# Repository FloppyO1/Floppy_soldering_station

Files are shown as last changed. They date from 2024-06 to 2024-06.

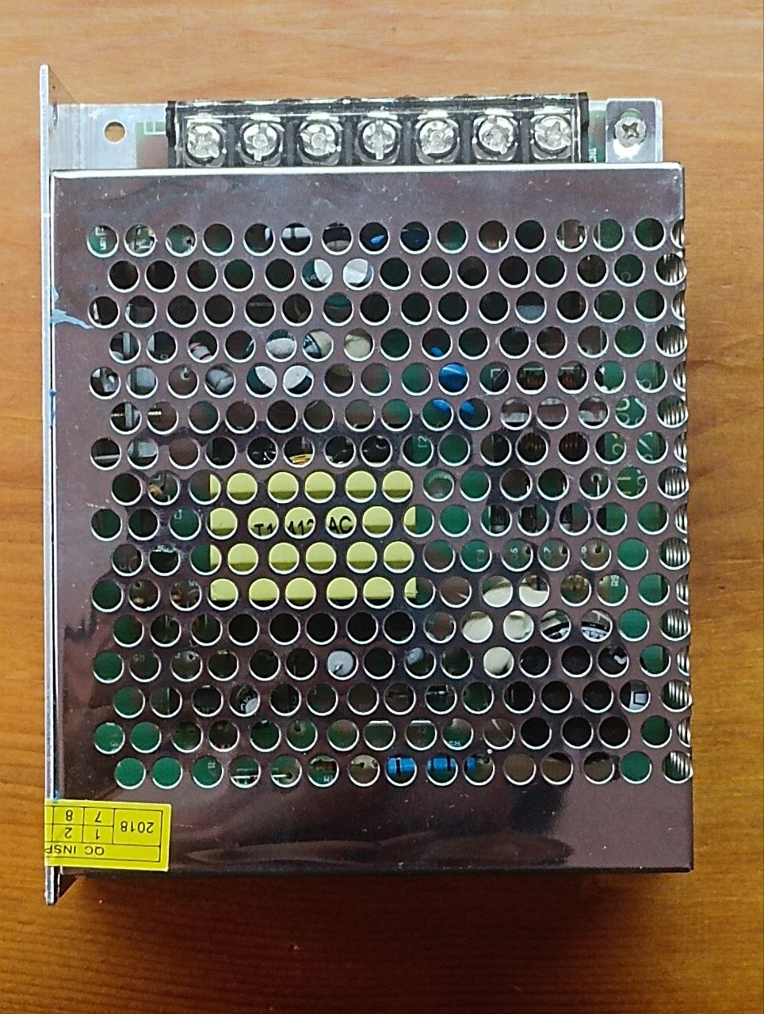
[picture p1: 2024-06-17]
CASE/components/power supply/up.jpg

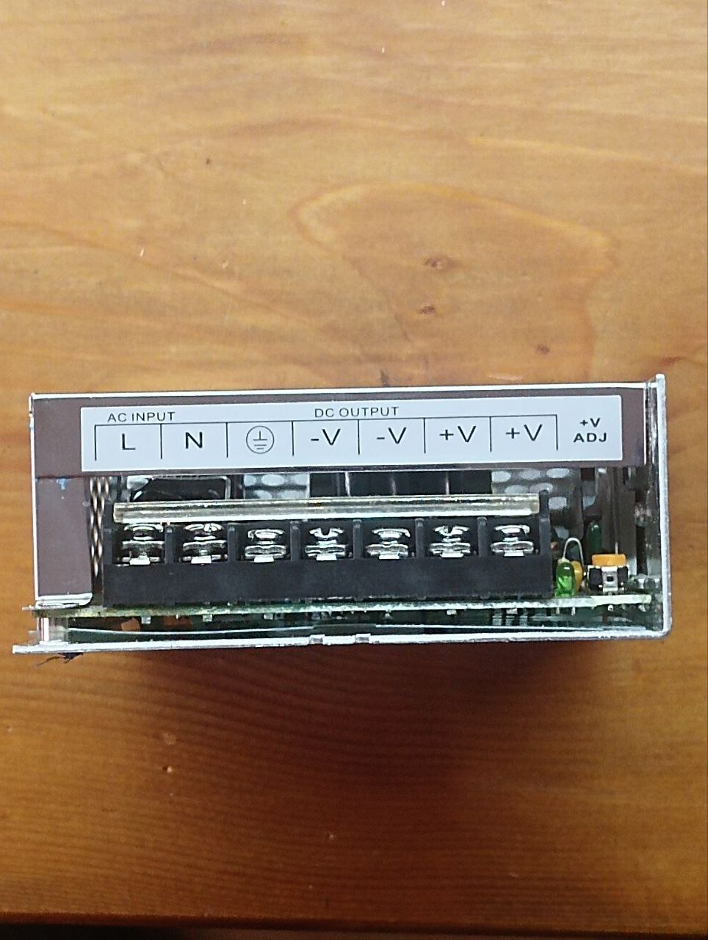
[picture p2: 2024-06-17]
CASE/components/power supply/front.jpg

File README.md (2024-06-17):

## Floppy Soldering Station v3.0
The Floppy soldering station 3.0 is a DIY soldering station, easy to make and inexpensive. It is great for learning and having a good workshop tool at the same time.





https://youtu.be/hezzL1TSIhk

## Support this project with a donation

To support this project you can make a donation via PayPal or buy a Floppy Board:

https://www.paypal.com/paypalme/floppylab

https://ko-fi.com/floppylab

## License

[CERN Open Hardware Licence Version 2 - Strongly Reciprocal](https://choosealicense.com/licenses/cern-ohl-s-2.0/#)



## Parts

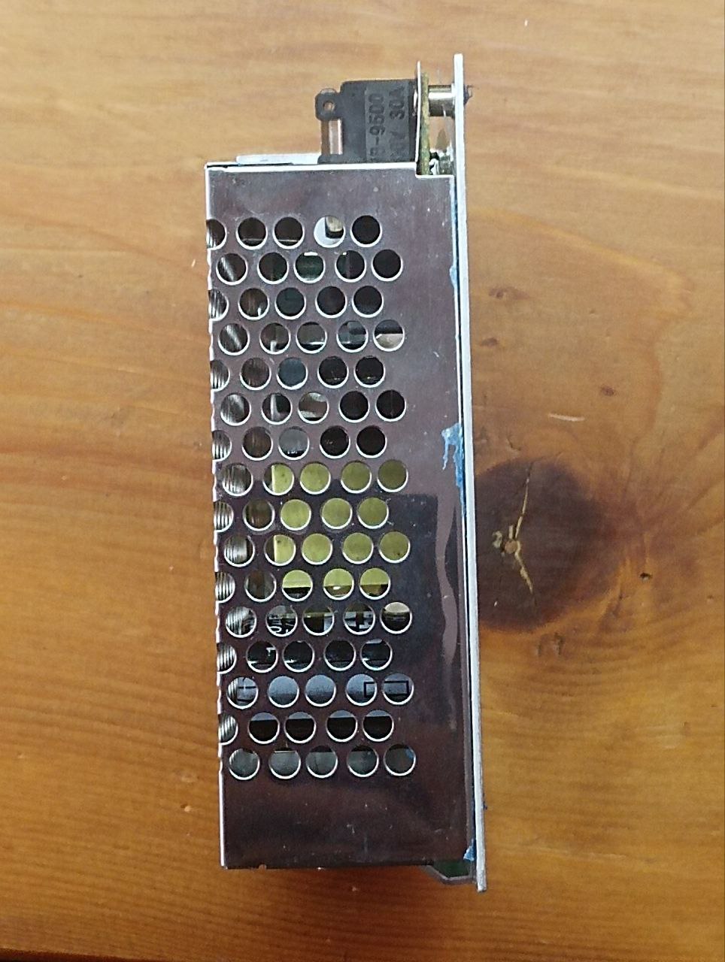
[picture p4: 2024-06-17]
CASE/components/power supply/right.jpg

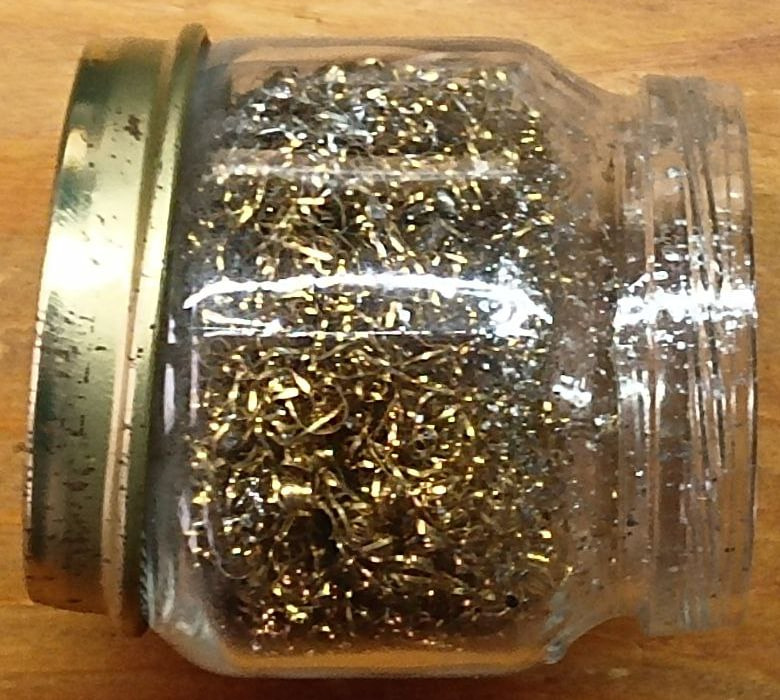
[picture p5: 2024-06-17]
CASE/components/brass scourer cup.jpg

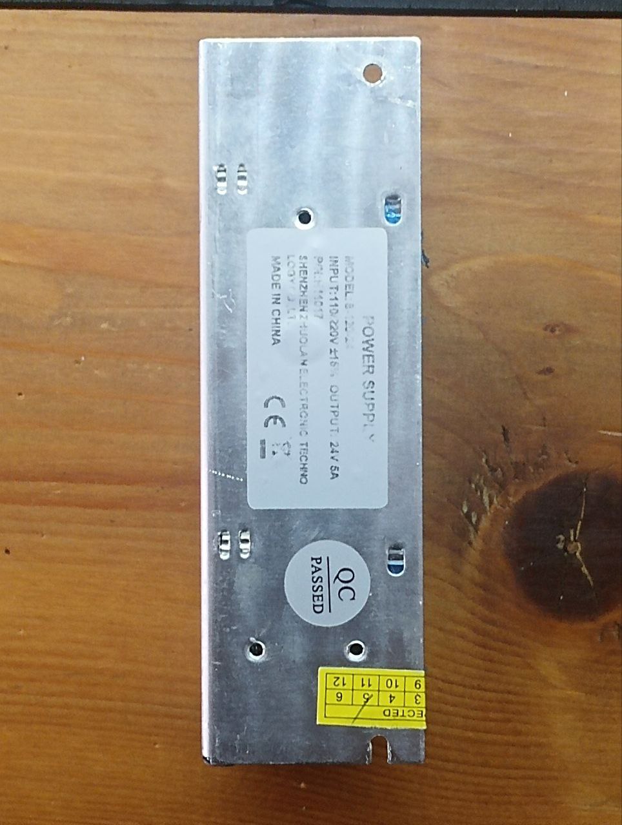
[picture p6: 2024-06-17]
CASE/components/power supply/left.jpg

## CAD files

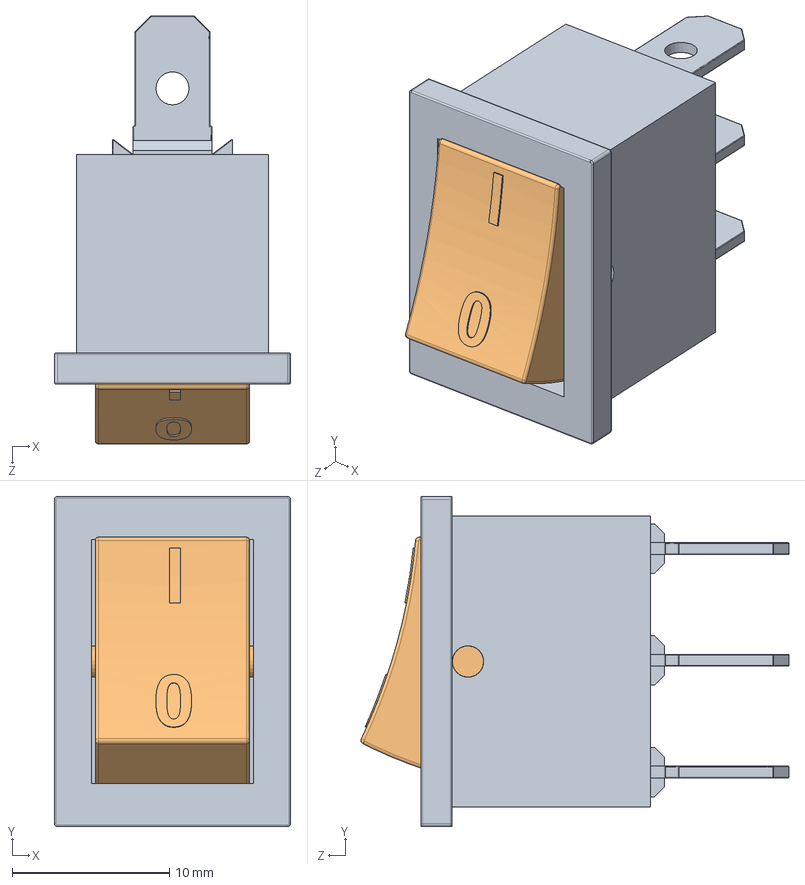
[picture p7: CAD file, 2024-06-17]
CASE/components/Power Switch.SLDASM
15.0 x 21.0 x 27.2 mm
F6vde.stp
Lambalı Anahtar - Tuş.stp
Lambalı Anahtar - Tuş arkası.stp

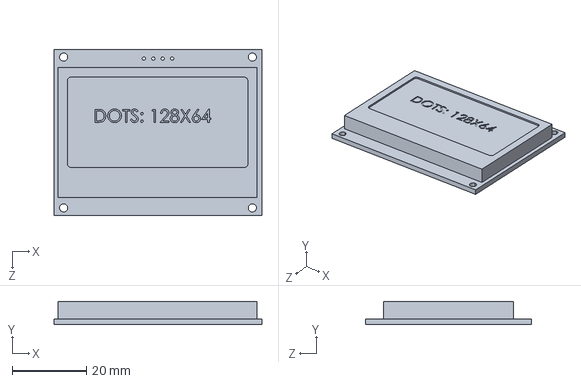
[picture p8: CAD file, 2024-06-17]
CASE/components/LCD-GM12864-59N.SLDPRT
56.0 x 6.30 x 44.6 mm

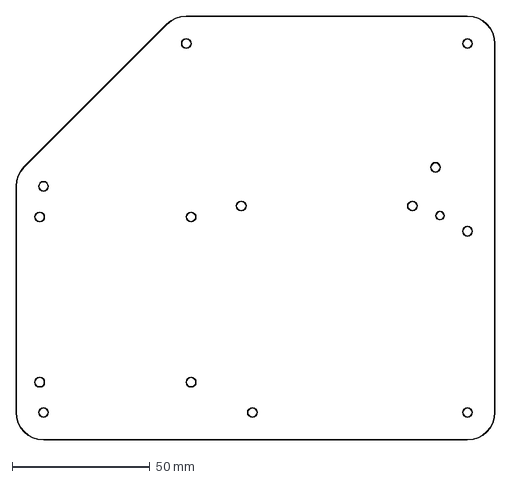
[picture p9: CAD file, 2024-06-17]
CASE/laser/case right.DXF
174.0 x 154.0 mm

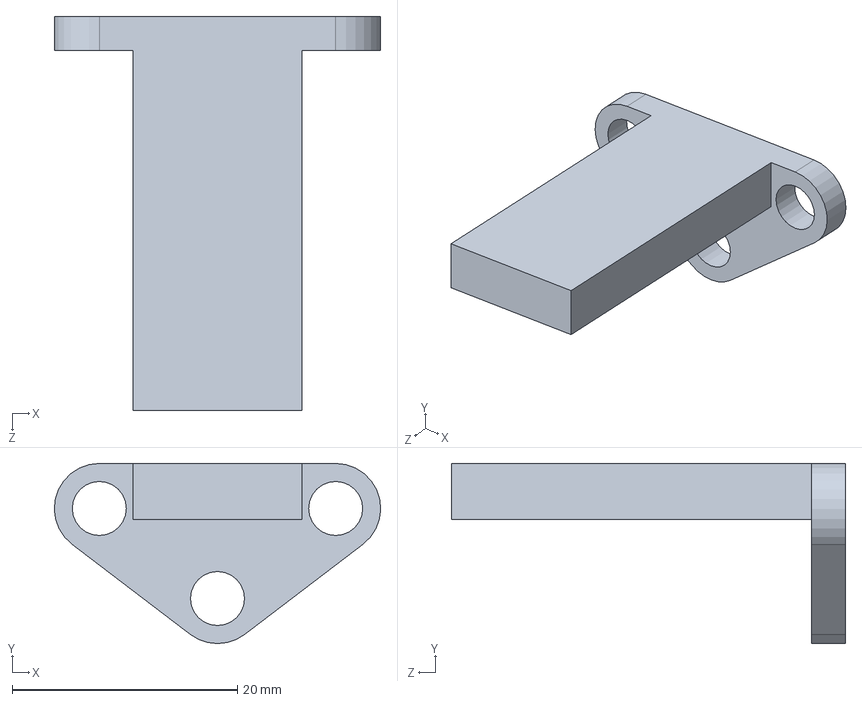
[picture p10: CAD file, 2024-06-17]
CASE/power supply holder 2.SLDPRT
29.0 x 16.0 x 35.0 mm

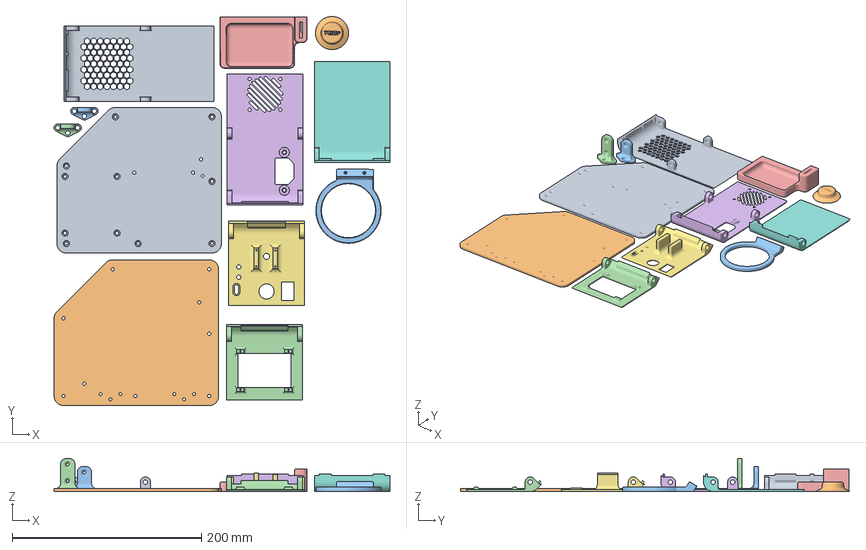
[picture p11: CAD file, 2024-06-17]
CASE/to be printed/case.3MF
355.1 x 411.2 x 35.0 mm

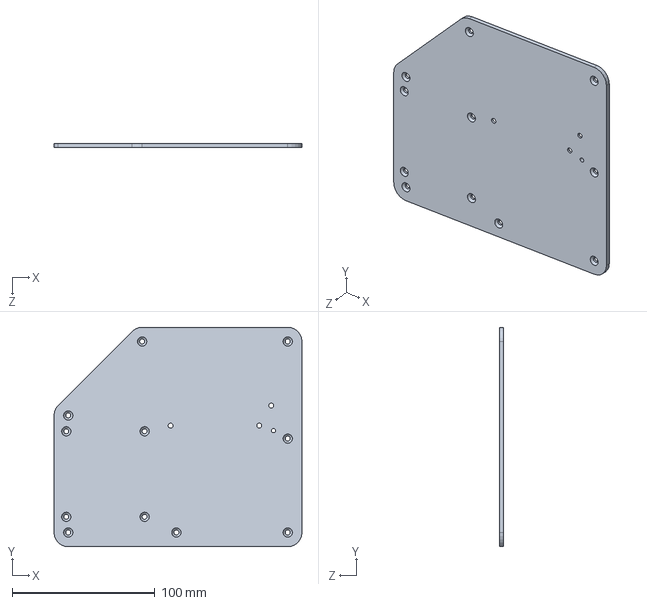
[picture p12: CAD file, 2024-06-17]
CASE/case right.SLDPRT
174.0 x 154.0 x 3.00 mm

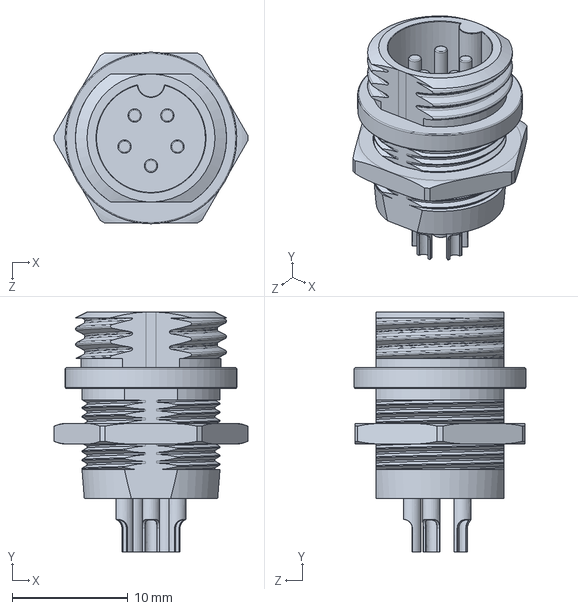
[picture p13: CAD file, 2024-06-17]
CASE/components/GX12-5P .SLDPRT
16.7 x 20.7 x 14.8 mm

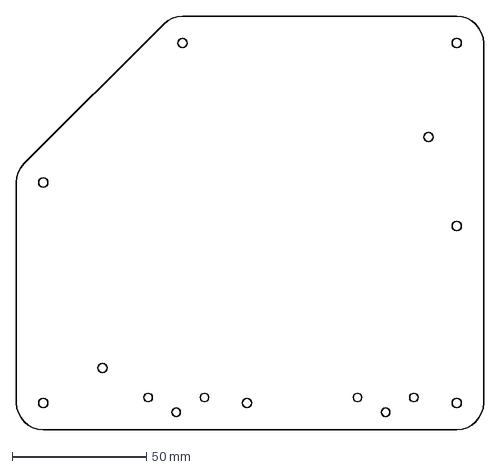
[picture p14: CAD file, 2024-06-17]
CASE/laser/case left.DXF
174.0 x 154.0 mm

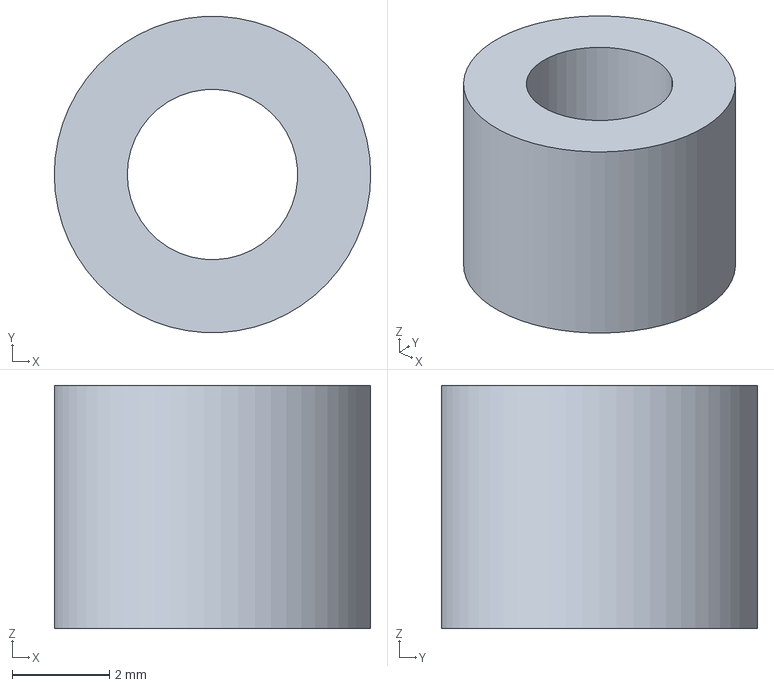
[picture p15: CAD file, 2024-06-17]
CASE/to be printed/PCB spacer.3MF
6.50 x 6.49 x 5.00 mm

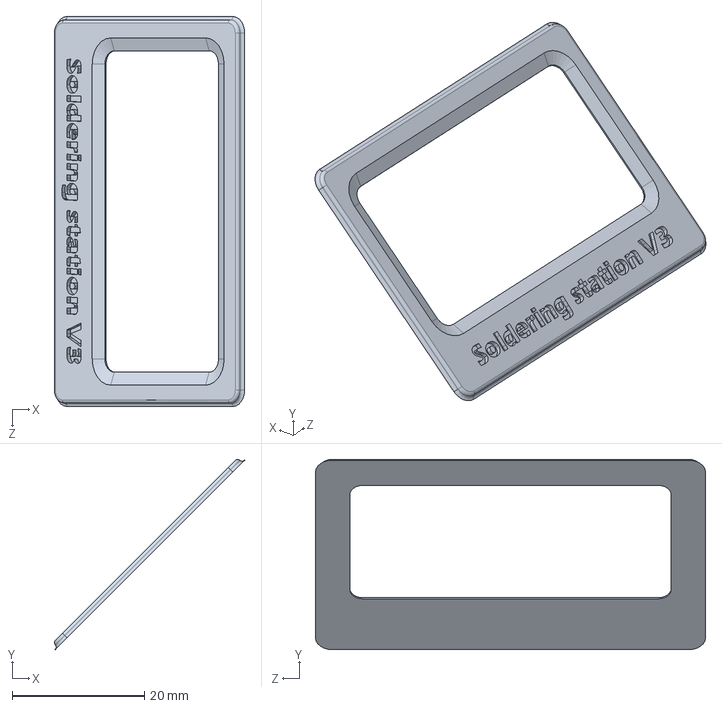
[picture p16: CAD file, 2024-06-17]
CASE/display mask.SLDPRT
28.8 x 28.8 x 59.0 mm

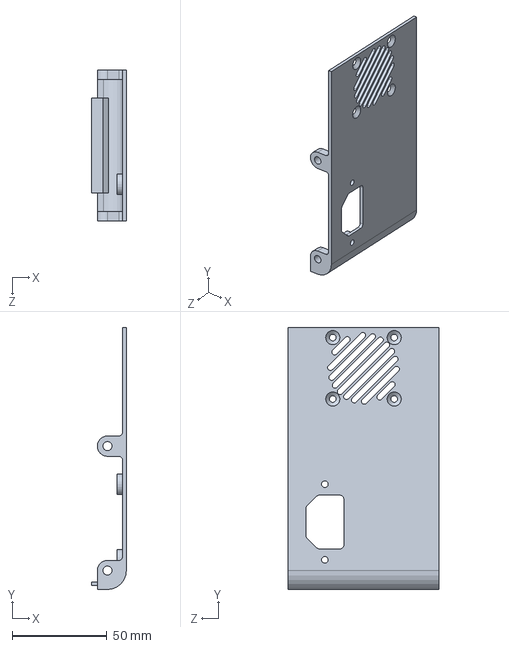
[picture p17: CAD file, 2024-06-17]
CASE/case 4.SLDPRT
18.4 x 138.6 x 80.0 mm

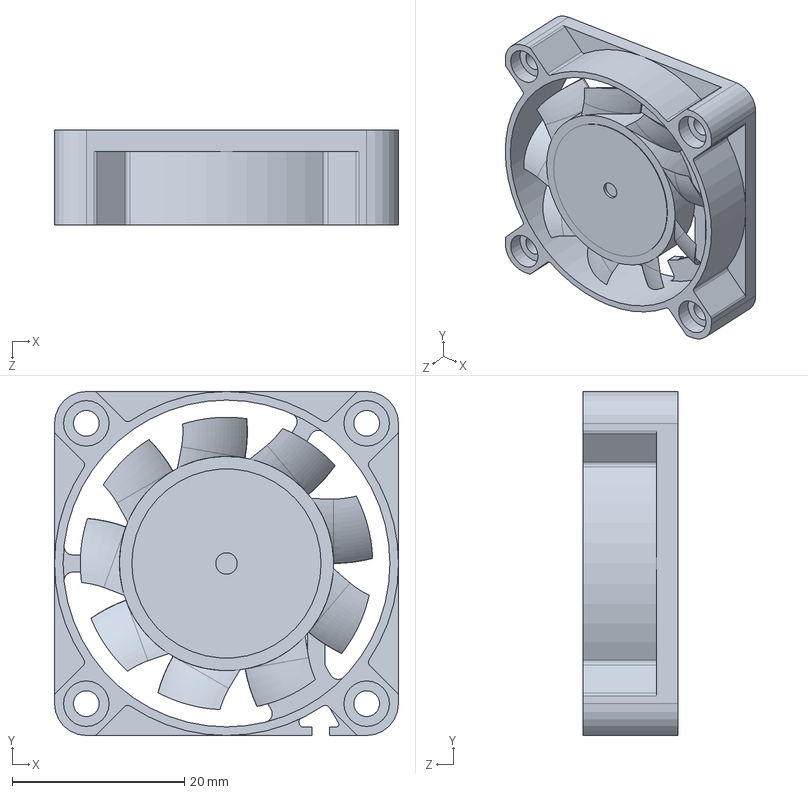
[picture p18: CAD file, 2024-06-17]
CASE/components/40x40x10 fan.SLDPRT
40.0 x 40.0 x 11.0 mm

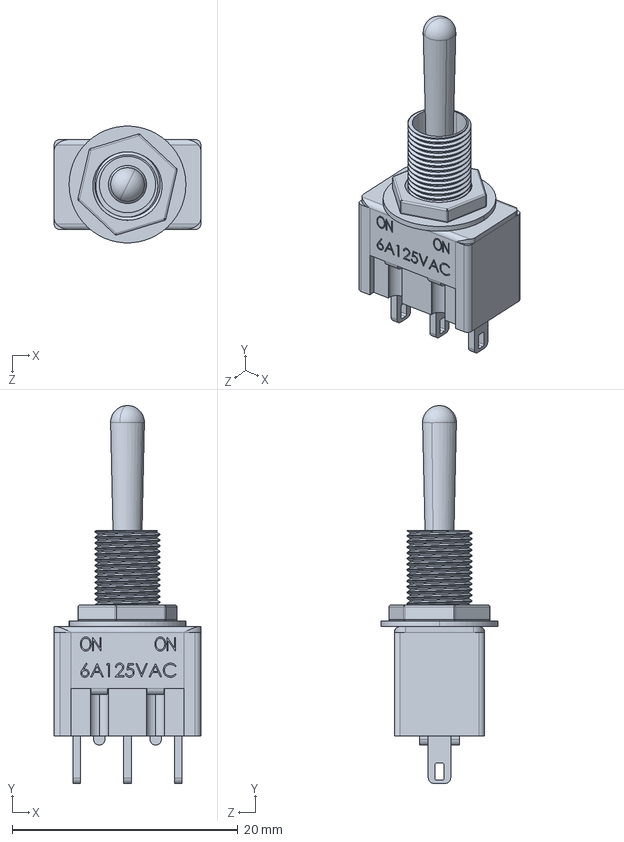
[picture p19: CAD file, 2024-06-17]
CASE/components/lever switch.SLDPRT
13.0 x 33.5 x 10.3 mm

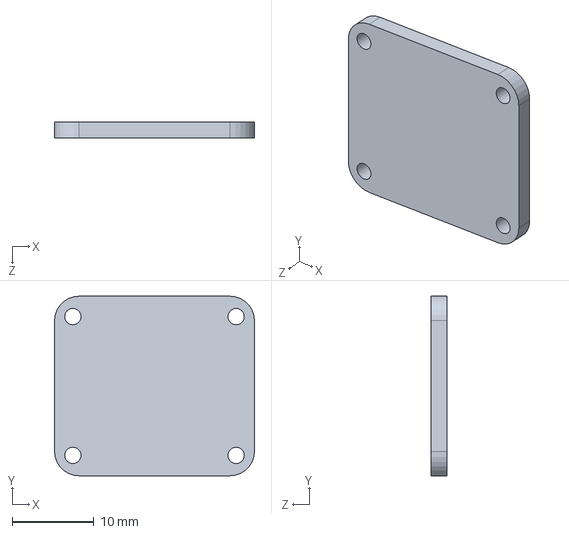
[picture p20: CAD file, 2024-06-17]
CASE/encoder holder.SLDPRT
24.5 x 22.0 x 2.00 mm

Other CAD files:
CASE/components/GX16-4P.SLDPRT
CASE/soldering iron holder.SLDPRT
CASE/components/C14 power plug.SLDPRT
CASE/power supply holder.SLDPRT
CASE/PCB_spacer.SLDPRT
CASE/brass scourer holder.SLDPRT
CASE/case 1.SLDPRT
CASE/case 2.SLDPRT
CASE/case 3.SLDPRT
CASE/case 5.SLDPRT
CASE/case base.SLDPRT
CASE/case left.SLDPRT
CASE/components/rotary+encoder_17mm_hole_spc.SLDPRT
CASE/knob.SLDPRT

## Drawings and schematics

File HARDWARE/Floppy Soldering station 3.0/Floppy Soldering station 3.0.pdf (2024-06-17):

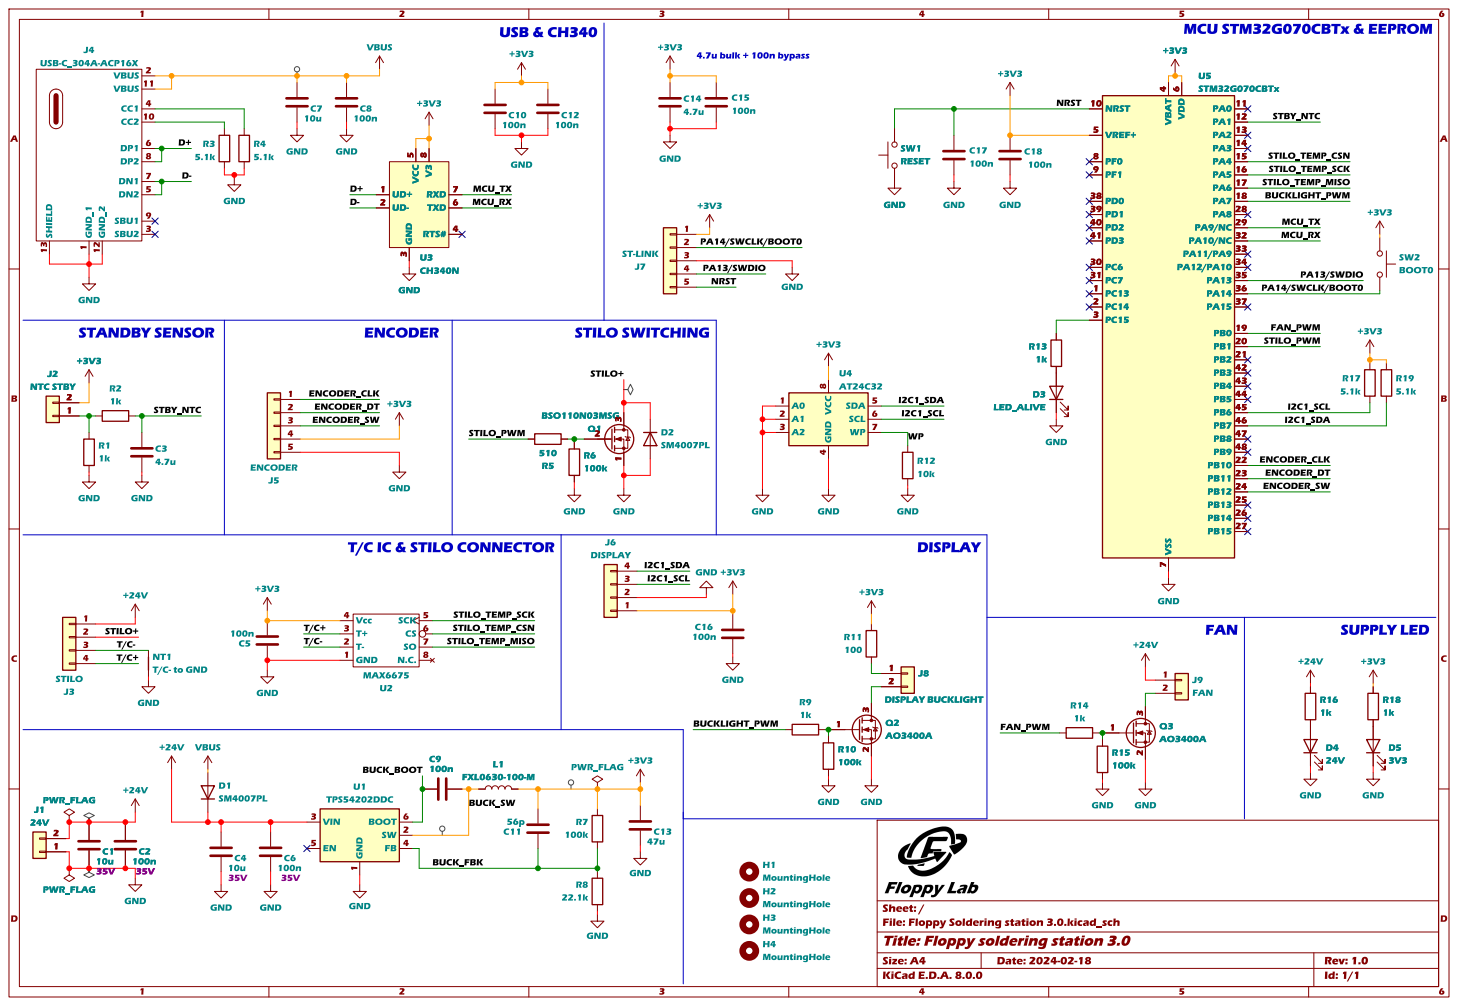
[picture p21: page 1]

File: Floppy Soldering station 3.0.kicad_sch Sheet: /
Id: 1/1 Title: Floppy soldering station 3.0

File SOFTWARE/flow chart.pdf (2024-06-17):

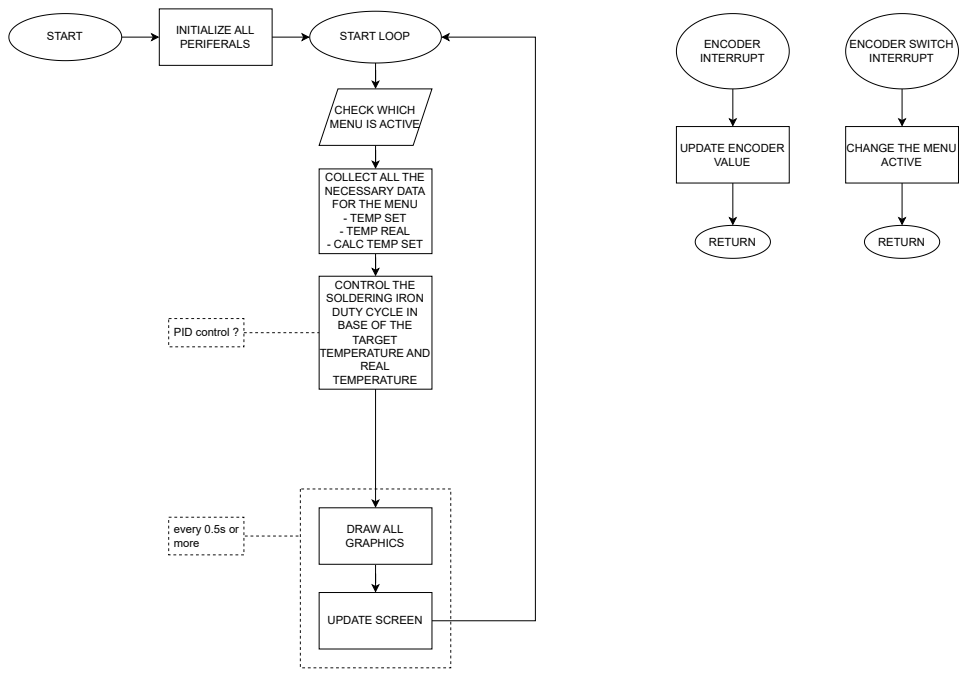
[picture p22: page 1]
START; INITIALIZE ALL; PERIFERALS; START LOOP; DRAW ALL GRAPHICS; UPDATE SCREEN; ENCODER INTERRUPT; UPDATE ENCODER VALUE; ENCODER SWITCH INTERRUPT; RETURN; REAL TEMPERATURE; every 0.5s or more; PID control ?

CHECK WHICH
MENU IS ACTIVE

CHANGE THE MENU
ACTIVE

COLLECT ALL THE
NECESSARY DATA
FOR THE MENU
- TEMP SET
- TEMP REAL
- CALC TEMP SET

CONTROL THE
SOLDERING IRON
DUTY CYCLE IN
BASE OF THE
TARGET
TEMPERATURE AND

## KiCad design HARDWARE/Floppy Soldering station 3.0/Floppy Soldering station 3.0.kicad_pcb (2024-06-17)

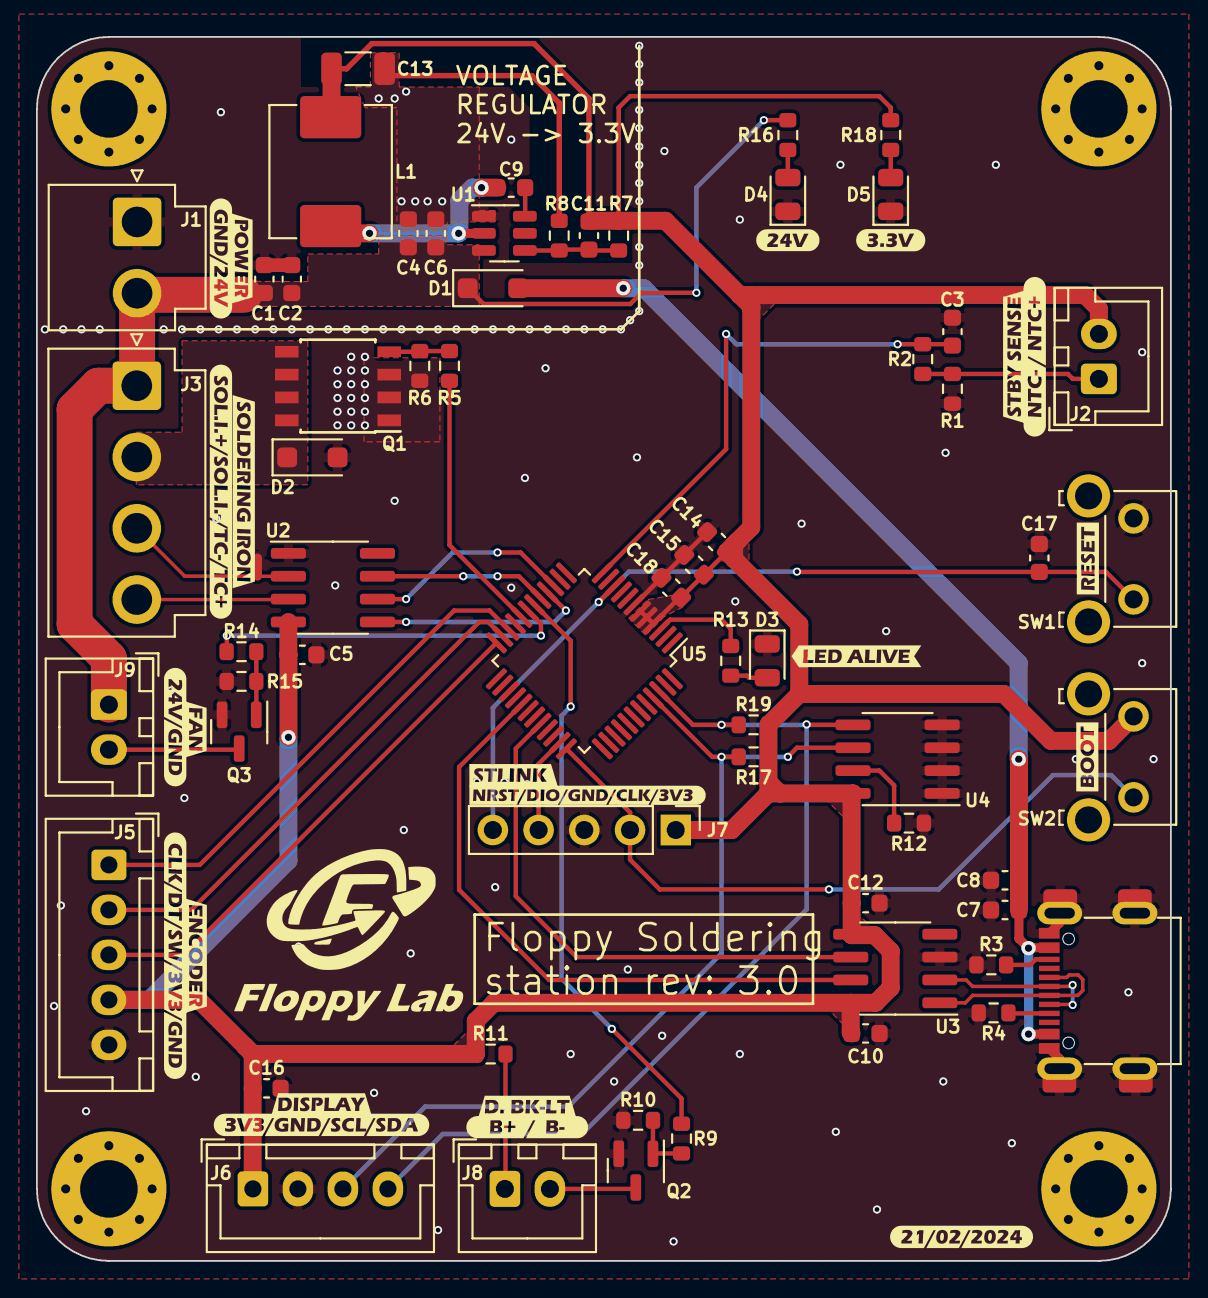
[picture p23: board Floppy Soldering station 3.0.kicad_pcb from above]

Board: 2 copper layers, 63.0 x 68.0 mm, 89 parts (0 on the bottom side), 43 nets.

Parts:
C1, C4, C7: 10u; C_0603_1608Metric
C2, C5, C6, C8, C9, C10, C12, C15, C16, C17, C18: 100n; C_0603_1608Metric
C3, C14: 4.7u; C_0603_1608Metric
C11: 56p; C_0603_1608Metric
C13: 47u; C_1206_3216Metric
D1, D2: SM4007PL; D_SOD-123F
D3: LED_ALIVE; LED_0805_2012Metric
D4: 24V; LED_0805_2012Metric
D5: 3V3; LED_0805_2012Metric
H1, H2, H3, H4: MountingHole; MountingHole_3.2mm_M3_Pad_Via
J1: 24V; JST_VH_B2P-VH-B_1x02_P3.96mm_Vertical
J2: NTC STBY; JST_XH_B2B-XH-A_1x02_P2.50mm_Vertical
J3: STILO; JST_VH_B4P-VH-B_1x04_P3.96mm_Vertical
J4: USB-C_304A-ACP16X; USB_C_304A-ACP16X
J5: ENCODER; JST_XH_B5B-XH-A_1x05_P2.50mm_Vertical
J6: DISPLAY; JST_XH_B4B-XH-A_1x04_P2.50mm_Vertical
J7: ST-LINK; PinHeader_1x05_P2.54mm_Vertical
J8: DISPLAY BUCKLIGHT; JST_XH_B2B-XH-A_1x02_P2.50mm_Vertical
J9: FAN; JST_XH_B2B-XH-A_1x02_P2.50mm_Vertical
L1: FXL0630-100-M; L_Abracon_ASPI-0630LR
NT1: T/C- to GND; NetTie-2_SMD_Pad0.5mm
Q1: BSO110N03MSG; PG-DSO-8
Q2, Q3: AO3400A; SOT-23
R1, R2, R9, R13, R14, R16, R18: 1k; R_0603_1608Metric
R3, R4, R17, R19: 5.1k; R_0603_1608Metric
R5: 510; R_0603_1608Metric
R6, R7, R10, R15: 100k; R_0603_1608Metric
R8: 22.1k; R_0603_1608Metric
R11: 100; R_0603_1608Metric
R12: 10k; R_0603_1608Metric
SW1: RESET; SW_SPST_Omron_B3F-315x_Angled
SW2: BOOT0; SW_SPST_Omron_B3F-315x_Angled
U1: TPS54202DDC; SOT-23-6
U2: MAX6675; SOIC-8_3.9x4.9mm_P1.27mm
U3: CH340N; SOIC-8_3.9x4.9mm_P1.27mm
U4: AT24C32; SOIC-8_3.9x4.9mm_P1.27mm
U5: STM32G070CBTx; LQFP-48_7x7mm_P0.5mm
kibuzzard-65D5CE26: G***; kibuzzard-65D5CE26
kibuzzard-65D5CEBD: G***; kibuzzard-65D5CEBD
kibuzzard-65D5D1B7: G***; kibuzzard-65D5D1B7
kibuzzard-65D5D1D2: G***; kibuzzard-65D5D1D2
kibuzzard-65D5D3BD: G***; kibuzzard-65D5D3BD
kibuzzard-65D5D3CA: G***; kibuzzard-65D5D3CA
kibuzzard-65D5D4B6: G***; kibuzzard-65D5D4B6
kibuzzard-65D5D4FE: G***; kibuzzard-65D5D4FE
kibuzzard-65D5D5E6: G***; kibuzzard-65D5D5E6
kibuzzard-65D5D7D5: G***; kibuzzard-65D5D7D5
kibuzzard-65D5D7E7: G***; kibuzzard-65D5D7E7
kibuzzard-65D5D32E: G***; kibuzzard-65D5D32E
kibuzzard-65D5D52E: G***; kibuzzard-65D5D52E
kibuzzard-65D5D69C: G***; kibuzzard-65D5D69C
kibuzzard-65D5D154: G***; kibuzzard-65D5D154
kibuzzard-65D5D342: G***; kibuzzard-65D5D342
kibuzzard-65D5D366: G***; kibuzzard-65D5D366
kibuzzard-65D5D519: G***; kibuzzard-65D5D519
kibuzzard-65D5D545: G***; kibuzzard-65D5D545
kibuzzard-65D5D557: G***; kibuzzard-65D5D557
kibuzzard-65D5D985: G***; kibuzzard-65D5D985
kibuzzard-65D705D3: G***; kibuzzard-65D705D3

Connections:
+3V3: C5.2, C10.1, C11.2, C12.1, C13.1, C14.1, C15.1, C16.1, C18.2, J2.2, J5.4, J6.1, J7.1, L1.2, R7.2, R11.2, R17.2, R18.1, R19.1, SW2.1, U2.4 (Vcc), U3.5 (VCC), U3.8 (V3), U4.8 (VCC), U5.4 (VBAT), U5.5 (VREF+), U5.6 (VDD)
+24V: C1.1, C2.1, C4.1, C6.1, D1.1 (K), J1.2, J3.1, J9.1, R16.1, U1.3 (VIN)
/BUCKLIGHT_PWM: R9.2, U5.18 (PA7)
/BUCK_BOOT: C9.2, U1.6 (BOOT)
/BUCK_FBK: C11.1, R7.1, R8.2, U1.4 (FB)
/BUCK_SW: C9.1, L1.1, U1.2 (SW)
/D+: J4.6 (DP1), J4.8 (DP2), U3.1 (UD+)
/D-: J4.5 (DN2), J4.7 (DN1), U3.2 (UD-)
/ENCODER_CLK: J5.1, U5.22 (PB10)
/ENCODER_DT: J5.2, U5.23 (PB11)
/ENCODER_SW: J5.3, U5.24 (PB12)
/FAN_PWM: R14.2, U5.19 (PB0)
/I2C1_SCL: J6.3, R17.1, U4.6 (SCL), U5.45 (PB6)
/I2C1_SDA: J6.4, R19.2, U4.5 (SDA), U5.46 (PB7)
/MCU_RX: U3.6 (TXD), U5.32 (PA10/NC)
/MCU_TX: U3.7 (RXD), U5.29 (PA9/NC)
/NRST: C17.1, J7.5, SW1.2, U5.10 (NRST)
/PA13/SWDIO: J7.4, U5.35 (PA13)
/PA14/SWCLK/BOOT0: J7.2, SW2.2, U5.36 (PA14)
/STBY_NTC: C3.1, R2.2, U5.12 (PA1)
/STILO+: D2.1 (K), J3.2, Q1.3 (D)
/STILO_PWM: R5.1, U5.20 (PB1)
/STILO_TEMP_CSN: U2.6 (CS), U5.15 (PA4)
/STILO_TEMP_MISO: U2.7 (SO), U5.17 (PA6)
/STILO_TEMP_SCK: U2.5 (SCK), U5.16 (PA5)
/T/C+: J3.4, U2.3 (T+)
/T/C-: J3.3, NT1.2, U2.2 (T-)
/WP: R12.1, U4.7 (WP)
GND: C1.2, C2.2, C3.2, C4.2, C5.1, C6.2, C7.2, C8.2, C10.2, C12.2, C13.2, C14.2, C15.2, C16.2, C17.2, C18.1, D2.2 (A), D3.1 (K), D4.1 (K), D5.1 (K), J1.1, J4.1 (GND_1), J4.12 (GND_2), J4.13 (SHIELD), J5.5, J6.2, J7.3, NT1.1, Q1.1 (S), Q2.2 (S), Q3.2 (S), R1.2, R3.1, R4.2, R6.2, R8.1, R10.2, R12.2, R15.2, SW1.1, U1.1 (GND), U2.1 (GND), U3.3 (GND), U4.1 (A0), U4.2 (A1), U4.3 (A2), U4.4 (GND), U5.7 (VSS)
unnamed: D3.2 (A), R13.2
unnamed: D4.2 (A), R16.2
unnamed: D5.2 (A), R18.2
unnamed: J2.1, R1.1, R2.1
unnamed: J4.4 (CC1), R4.1
unnamed: J4.10 (CC2), R3.2
unnamed: J8.1, R11.1
unnamed: J8.2, Q2.3 (D)
unnamed: J9.2, Q3.3 (D)
unnamed: Q1.2 (G), R5.2, R6.1
unnamed: Q2.1 (G), R9.1, R10.1
unnamed: Q3.1 (G), R14.1, R15.1
unnamed: R13.1, U5.3 (PC15)
VBUS: C7.1, C8.1, D1.2 (A), J4.2 (VBUS), J4.11 (VBUS)

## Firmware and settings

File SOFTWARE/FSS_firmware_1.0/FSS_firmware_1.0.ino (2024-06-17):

/*
This code was written by Floppy Lab for the Floppy Soldering Station 3.0
This code is under license (check it on the github folder)
https://github.com/FloppyO1/Floppy_soldering_station.git
*/

#include <U8g2lib.h>
#include <Wire.h>
#include <max6675.h>
#include <SparkFun_External_EEPROM.h>
#include <PID_v1.h>
#include <OneButton.h>
//#include "FSS_function_definitions.h"

#define DEBUG 1

#if DEBUG == 1
#define Debug(x) Serial.print(x)
#define Debugln(x) Serial.println(x)
#else
#define Debug(x)
#define Debugln(x)
#endif

/* PINS */
// DISPLAY
#define SDA PB7            // I2C
#define SCL PB6            // I2C
#define PWM_BUCKLIGHT PA7  // PWM OUTPUT
// STBY NTC
#define NTC_STBY PA1  // ADC
// T/C
#define TC_CS PA4   // SPI
#define TC_DO PA6   // SPI
#define TC_CLK PA5  // SPI
// UART
#define UART_TX PA9   // UART
#define UART_RX PA10  // UART
// FAN
#define FAN_PWM PB0  // PWM OUTPUT
// HEATER
#define HEATER_PWM PB1  // PWM OUTPUT
// ENCODER
#define ENCODER_CLK PB10  // I/O INPUT
#define ENCODER_DT PB11   // I/O INPUT
#define ENCODER_SW PB12   // I/O INPUT
// LED
#define LED_ALIVE PC15  // I/O OUTPUT

// SETTINGS
#define ENCODER_SENSITIVITY 1  // bigger the number, smaller the sensitivity
#define FPS_DISPLAY 5
#define TC_RATE 2
#define MENU_NAME_TIME 500
#define FAN_SPEED 255

#define REAL_TEMP_FILTER 0.2

#define MAX_SETTABLE_TEMP 450
#define MIN_SETTABLE_TEMP 100
#define TEMP_SET_STEP 5

#define HEATER_PWM_FREQUENCY 10
#define AGGRESSIVE_KP 4
#define AGGRESSIVE_KI 0.2
#define AGGRESSIVE_KD 50
#define CONSERVATIVE_KP 4
#define CONSERVATIVE_KI 0.1
#define CONSERVATIVE_KD 200
#define PID_CANGE_LEVEL 100    // error at which the pid constant change to conservative

// TIPES
enum Menu {
  MENU_MAIN,
  MENU_SET_TEMP
};

enum State {
  USING,      // soldering iron in hand
  NOT_USING,  // soldering iron in holder
  STBY,       // soldering station in stby (iron in holder for lot of time)
  TC_ERR      // T/C not found
};

// GRAPHIC VARIABLES
uint8_t gif2 = 0;

// GLOBAL VARIABLES
int encoderCount = 0;
Menu menuActive = MENU_MAIN;
Menu menuPerv = MENU_MAIN;
State status = STBY;
double targetTemp = 300;
double realTemp = 0;
double solderingDuty = 0;
bool solderingEN = false;
//double realTempPrev = 0;

// T/C OBJECT
MAX6675 thermocouple(TC_CLK, TC_CS, TC_DO);
// DISPLAY OBJECT
U8G2_ST7567_ENH_DG128064I_F_HW_I2C display(U8G2_R2);  // [page buffer, size = 128 bytes]
// EXTERNAL EEPROM OBJECT
ExternalEEPROM myMem;
// PID OBJECT
double aggKp = AGGRESSIVE_KP, aggKi = AGGRESSIVE_KI, aggKd = AGGRESSIVE_KD;
double consKp = CONSERVATIVE_KP, consKi = CONSERVATIVE_KI, consKd = CONSERVATIVE_KD;
PID heaterPID(&realTemp, &solderingDuty, &targetTemp, consKp, consKi, consKd, DIRECT);
OneButton EncoderButton(ENCODER_SW, true);


void setup() {
  initSerial();
  initDisplay();
  initEncoder();
  initSolderingIron();
  initFan();

  setFanSpeed(FAN_SPEED);
  heaterPID.SetMode(AUTOMATIC);
}  // end setup


int timeDisplay = 0;
int timeTC = 0;
int timeGif = 0;
void loop() {
  	// BUTTONS
    EncoderButton.tick();


  // TERMOCOPUPLE
  if (millis() - timeTC >= 1000 / TC_RATE) {
    float temp = getTempC();
    if (!isnan(temp)) {
      realTemp = ((int)temp * REAL_TEMP_FILTER) + ((int)realTemp * (1 - REAL_TEMP_FILTER));
      //realTempPrev = realTemp;
    }
    timeTC = millis();
  }

  // GRAPHIC INTERFACE
  if (millis() - timeDisplay >= 1000 / FPS_DISPLAY) {
    //Debugln("aggiorno il display");
    changeMenu();
    switch (menuActive) {
      case MENU_MAIN:
        drawMainMenu();
        break;
      case MENU_SET_TEMP:
        drawSetTempMenu();
        break;
    }
    display.sendBuffer();  // transfer internal memory to the display
    timeDisplay = millis();
  }

  // GIFs
  if (millis() - timeGif >= 500) {
    gif2 = (gif2 + 1) % 2;
    timeGif = millis();
  }

  // SOLDERING IRON HEATER
  if (status != TC_ERR && menuActive != MENU_SET_TEMP) {
    Debugln("normal operation");
    switchOnHeater();
  } else {
    switchOffHeater();
#ifdef DEBUG
    if (status == TC_ERR) { Debugln("TC_ERR"); }
    if (menuActive == MENU_SET_TEMP) { Debugln("menu set temp"); }
#endif
  }

  if(menuActive == MENU_SET_TEMP){
    updateEncoder();
  }


  if (solderingEN) {  // soldering iron enabled set duty acording to pid
    Debugln("keeping temperature");
    keepTemp();
  } else {  // sodering iron is disabled set duty to 0
    solderingDuty = 0;
    analogWrite(0, HEATER_PWM);
  }
}  // end loop

/* ------------------------- GENERAL ------------------------- */
void initSerial() {
  Serial.setTx(UART_TX);
  Serial.setRx(UART_RX);
  Serial.begin(115200);
}

void initLed() {
  pinMode(LED_ALIVE, OUTPUT);
}

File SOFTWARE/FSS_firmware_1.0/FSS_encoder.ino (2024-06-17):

/*
This code was written by Floppy Lab for the Floppy Soldering Station 3.0
This code is under license (check it on the github folder)
https://github.com/FloppyO1/Floppy_soldering_station.git
*/

/* ------------------------- ENCODER ------------------------- */
void initEncoder() {
  pinMode(ENCODER_CLK, INPUT);
  pinMode(ENCODER_DT, INPUT);
  pinMode(ENCODER_SW, INPUT);
  EncoderButton.attachClick(encoderSW);
  //attachInterrupt(ENCODER_SW, encoderSW, FALLING);
}

int enSWlastPress = 0;
void encoderSW() {
  if (millis() - enSWlastPress >= 200) {
    digitalWrite(LED_ALIVE, 1);
    switch (menuActive) {
      case MENU_MAIN:  // if we are in the menu MAIN set the settings in SET_TEMP menu
        menuActive = MENU_SET_TEMP;
        setEncoder(targetTemp);  // set the encodercount to the target temp value
        break;
      case MENU_SET_TEMP:  // if we are in the menu SET_TEMP set the settings in MAIN menu
        menuActive = MENU_MAIN;
        targetTemp = getEncoder();  // set the target temperature to the value of the knob
        break;
    }
    digitalWrite(LED_ALIVE, 0);
    enSWlastPress = millis();
  }
}


int getEncoder() {
  return encoderCount / ENCODER_SENSITIVITY;
}

void setEncoder(int n) {
  encoderCount = n * ENCODER_SENSITIVITY;
}

void updateEncoder() {
  static uint8_t state = 0;
  bool CLKstate = digitalRead(ENCODER_CLK);
  bool DTstate = digitalRead(ENCODER_DT);
  switch (state) {
    case 0:             // Idle state, encoder not turning
      if (!CLKstate) {  // Turn clockwise and CLK goes low first
        state = 1;
      } else if (!DTstate) {  // Turn anticlockwise and DT goes low first
        state = 4;
      }
      break;
    // Clockwise rotation
    case 1:
      if (!DTstate) {  // Continue clockwise and DT will go low after CLK
        state = 2;
      }
      break;
    case 2:
      if (CLKstate) {  // Turn further and CLK will go high first
        state = 3;
      }
      break;
    case 3:
      if (CLKstate && DTstate) {  // Both CLK and DT now high as the encoder completes one step clockwise
        state = 0;
        encoderCount = incrementInsideLimit(encoderCount, MAX_SETTABLE_TEMP);
      }
      break;
    // Anticlockwise rotation
    case 4:  // As for clockwise but with CLK and DT reversed
      if (!CLKstate) {
        state = 5;
      }
      break;
    case 5:
      if (DTstate) {
        state = 6;
      }
      break;
    case 6:
      if (CLKstate && DTstate) {
        state = 0;
        encoderCount = decrementInsideLimit(encoderCount, MIN_SETTABLE_TEMP);
      }
      break;
  }
}

int incrementInsideLimit(int n, int max){
  int t = n;
  if(t+TEMP_SET_STEP < max){
    return t+TEMP_SET_STEP;
  }else{
    return n;
  }
}

int decrementInsideLimit(int n, int min){
  int t = n;
  if(t-TEMP_SET_STEP > min){
    return t-TEMP_SET_STEP;
  }else{
    return n;
  }
}

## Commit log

2024-06-17 Added all the files of the project
    [40x40x10 fan.SLDPRT, Assembly Floppy Soldering Station 3.0.3MF, C14 power plug.SLDPRT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]
2024-06-17 file for printing updated
    [Assembly Floppy Soldering Station 3.0.3MF, case 2.3MF, case.3MF]
